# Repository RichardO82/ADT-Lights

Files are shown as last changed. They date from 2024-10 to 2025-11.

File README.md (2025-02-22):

# ADT-Lights

Fish tank light with an LED Strip and additional ambient LEDs controlled by an ESP32 with Annual Daylight Timer (ADT) functionality.

Requires a power supply capable of continuously delivering 4 amps at 5 volts.  Also requires an LED Strip, UV LEDs, a Qwiic Pro Mini microcontroller, and a Qwiic Alphanumeric Display.

Power Supply:
https://www.digikey.com/en/products/detail/mean-well-usa-inc/LRS-35-5/7705043

LED Strip:
https://www.sparkfun.com/products/14015

UV LEDs:
https://www.sparkfun.com/products/8662

Qwiic Pro Mini:
https://www.sparkfun.com/products/23386

Display:
https://www.sparkfun.com/products/16916

All other components are listed in the BOM.  Hardware size is M3x16mm.

Initial Setup:
1.  Update SPIFFS_Uploader.ino with your network ssid and password and flash to ESP32 (configuration settings are in the comments at the top of in ADT_Lights.ino).  This is temporary, we will overwrite the program with ADT_Lights.ino in step 3.
2.  Upload index.html and faders.html to the ESP32 using the uploader.
3.  Flash ADT_Lights.ino to the ESP32.

Start-up and Configuration:

1.  Power on, wait for clock to display.
2.  Using a BLE Terminal App on your phone, find the BLE device "ESP32 LED Bar".
3.  Send your Wifi SSID and password through BLE serial:  To send SSID, send the string ".s[ssid]", where [ssid] is your SSID, for example if my SSID is "FBIVan34" I would send ".sFBIVan34" (without quotes).  Your terminal app may give errors, ignore them.
4.  To send password, send the string ".p[pass]", where [pass] is your password, for example if my password is "apass" I would send ".papass" (without quotes).  After this command the ESP32 will reboot.
5.  After reboot, the ESP32 will connect to your wifi and display it's IP address.  Reboot to display the IP address again if needed by disconnecting and reconnecting power.
6.  In a web browser, type the IP address in the address bar to navigate to the ESP32's webserver and configure the options.

  There are two lighting systems - ambient LEDs, and the LED strip.  The ambient LEDs are not addressable, but they are separated into UV and white channels.  The LED strip is addressable and is configured in a U shape with the 2nd half of the strip turned around and arranged next to the first half, so the strip is two LEDs thick.

  Of the 5 PCBs, one is almost fully populated with components except for two of the LED switching channels (BJT+FET) that arent' being used, while the other 4 PCBs are only populated with LEDs and their current limiting resistors.  Wires carry the drive current to the LEDs on each successive board.  The center LEDs have 3 channels, but they are all white, so I connected these together at the connector (J6 or J7), so I only have two channels (this is why "white" shows up in the code indexed as STRIP_R - I'm using the Red channel for all three).  Originally I wanted a bright white LED, so this is what I shopped for, but I noticed in the datasheet that it has 3 LEDs which are all broken out individually just like an RGB, so I made each one separately dimmable.  It's possible to swap the white LED for an RGB LED and use all 4 channels with minimal changes to the code, but for now everything is made to work with the parts listed using only the two channels for ambient lighting (UV and red for white).  So on the bottom side of the PCB, there are 4 clusters of components which are the BJTs and FETs which step up the signal from the uC and drive the LED channels.  Only the bottom two clusters, the ones that connect to pins 25 and 26 on the Qwiic Pro Mini, need to be populated.

  The PCB which is mostly populated also connects to and supplies power to the LED strip.  The last PCB at the opposite end of the bar is where the middle of the LED strip is split and connected in a U-turn to run back down the bar.  So there are a lot of footprints on the PCBs, but a lot of them are left unpopulated on most of the boards and are only used for specific purposes.  The LED strip will go over some of the unpopulated footprints.  It is important to keep the double sided sticky tape on the LED strip as insulation to prevent contact with the unpopulated footprints on the PCB, and also to secure the strip.

  A couple of things to note, the UV LEDs (sparkfun) have a less than ideal viewing angle (45 deg. on datasheet) that is essentially a narrow beam, so they don't fill the space well and give a striped look.  If there is a UV LED in the same package that has a higher viewing angle, that would be an improvement.  Also, a waterproof closure with UV transmissive acryllic is needed.

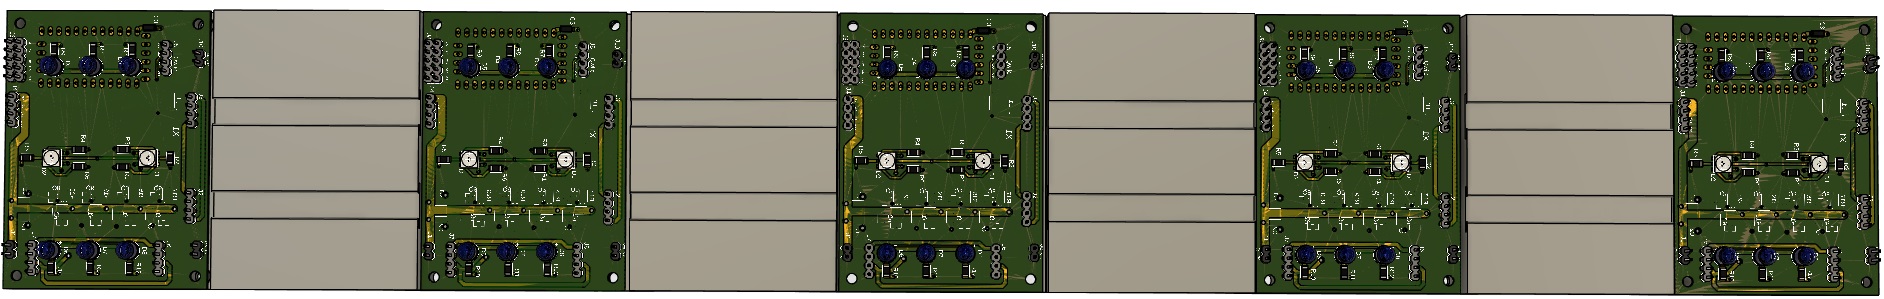
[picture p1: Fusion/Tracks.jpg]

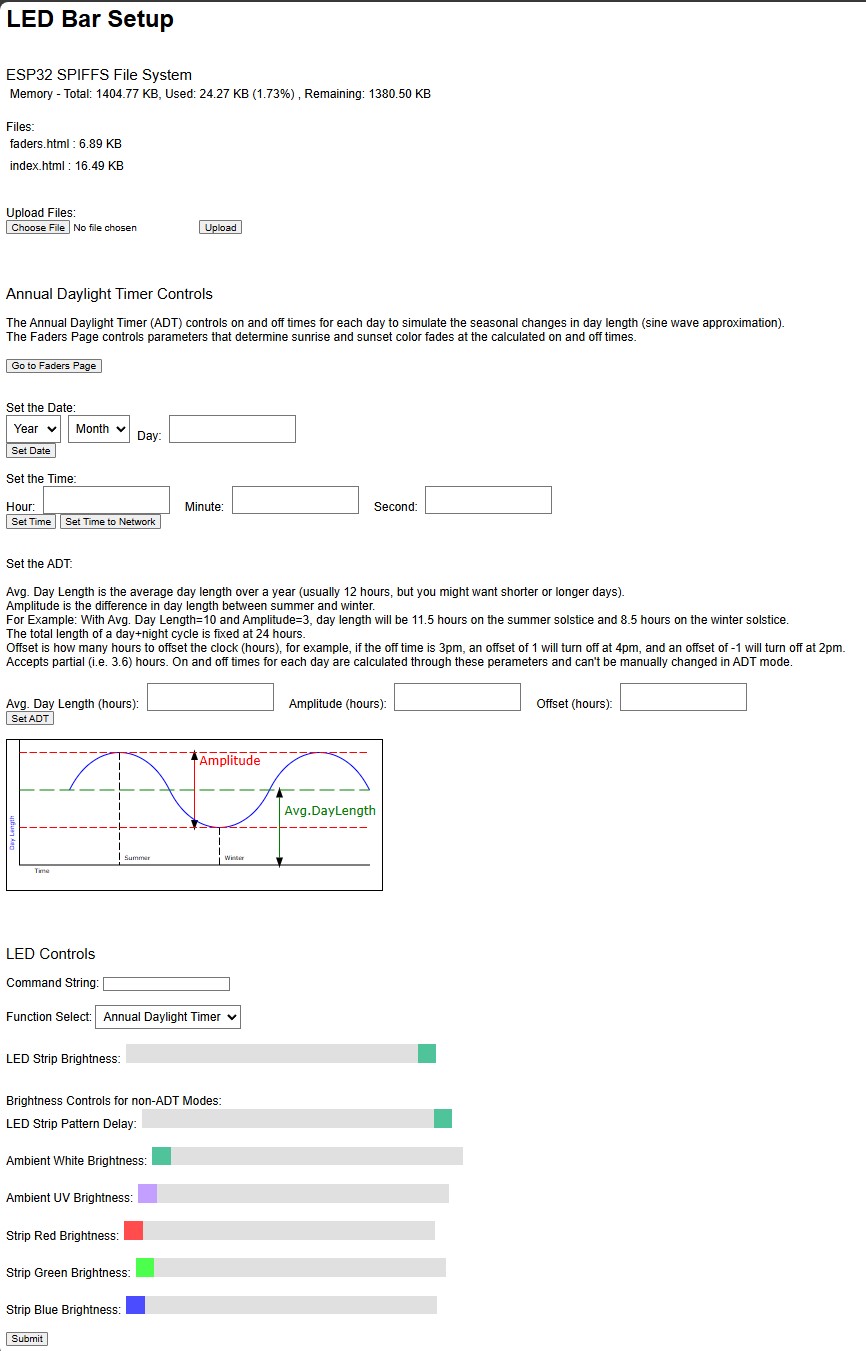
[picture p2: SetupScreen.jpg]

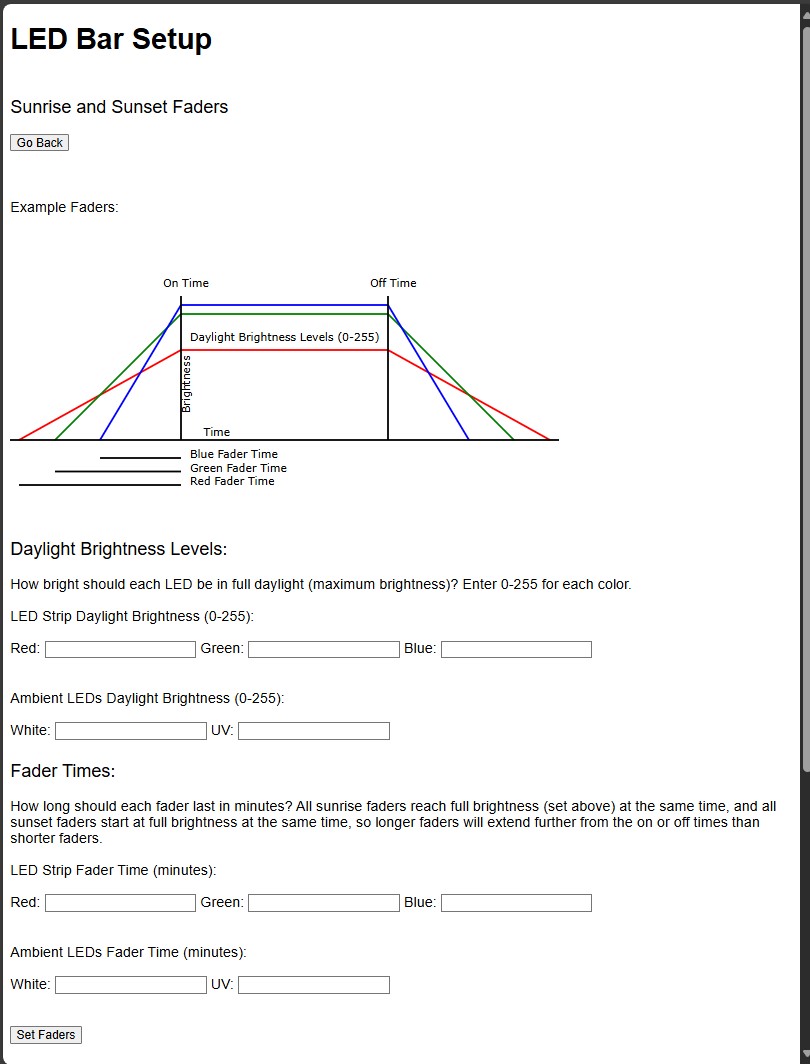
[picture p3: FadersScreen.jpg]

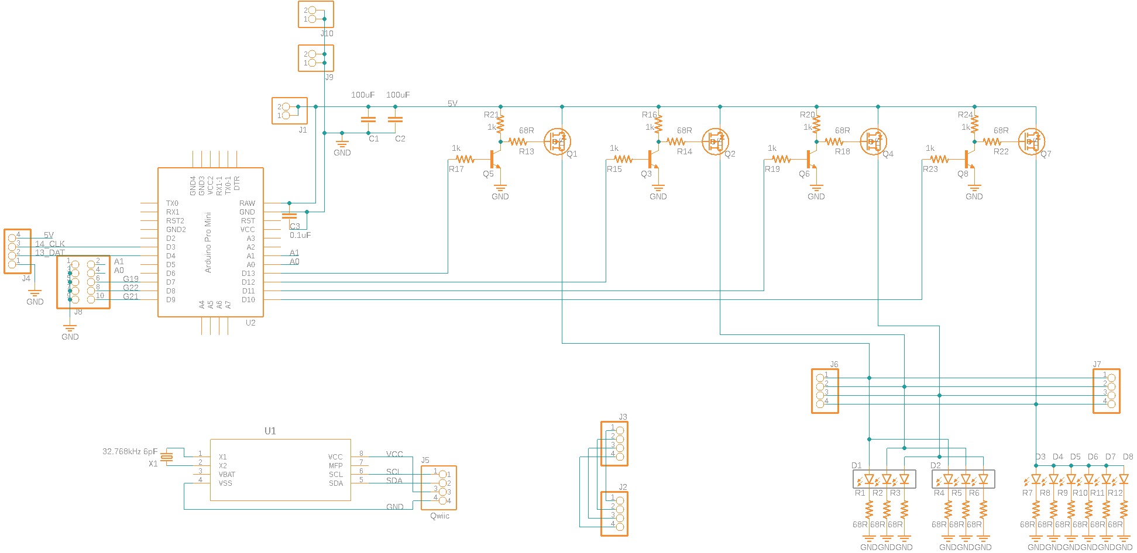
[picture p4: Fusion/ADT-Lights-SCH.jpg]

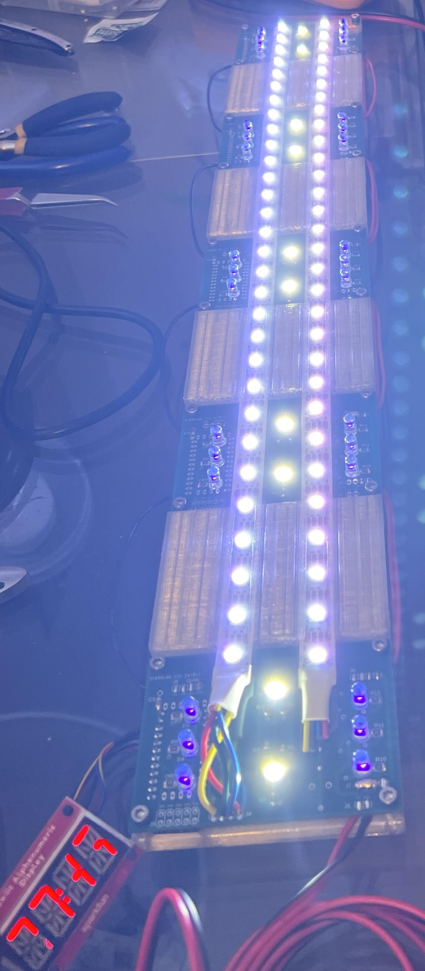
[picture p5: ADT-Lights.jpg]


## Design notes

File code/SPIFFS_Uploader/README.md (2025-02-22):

## Example 2 - Single Webpage, Authentication, File Management, Upload with Progress Bar
- web page authentication
- single webpage
- file listing button
- file download button
- file delete button
- file upload button
- reboot esp32 button
- all done on a single web page that updates webpage elements using javascript

## Configuration
Edit these variables at the beginning of SPIFFS_Uploader.ino

```
const String default_ssid = "somessid";
const String default_wifipassword = "mypassword";
const String default_httpuser = "admin";
const String default_httppassword = "admin";
const int default_webserverporthttp = 80;
```

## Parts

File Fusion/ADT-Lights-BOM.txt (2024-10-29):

"Part";"Value";"Device";"Package";"Description";"AVAILABILITY";"CATEGORY";"COPYRIGHT";"DESC";"DESCRIPTION";"MANUFACTURER";"MANUFACTURER_PART_NUMBER";"MF";"MFR_NAME";"MP";"MPN";"OPERATING_TEMP";"OPERATING_TEMPERATURE";"PACKAGE";"PART_STATUS";"PITCH";"PRICE";"RATING";"ROHS_COMPLIANCE";"ROHS_COMPLIANT";"SERIES";"SHOWNAME";"SUB-CATEGORY";"THERMALLOSS";"TOLERANCE";"TYPE";"VALUE";"VOLTAGE_RATING";
"C1";"100uF";"C_TANTALUM-1206(3216-METRIC)";"CAPM3216X180";"Capacitor - Generic";"";"Capacitor";"";"";"";"";"";"";"";"";"";"";"";"";"";"";"";"";"";"";"";"";"";"";"";"";"";"";
"C2";"100uF";"C_TANTALUM-1206(3216-METRIC)";"CAPM3216X180";"Capacitor - Generic";"";"Capacitor";"";"";"";"";"";"";"";"";"";"";"";"";"";"";"";"";"";"";"";"";"";"";"";"";"";"";
"C3";"0.1uF";"C_TANTALUM-1206(3216-METRIC)";"CAPM3216X180";"Capacitor - Generic";"";"Capacitor";"";"";"";"";"";"";"";"";"NMC1206X7R104K50TRPF";"";"";"";"";"";"";"";"";"";"";"";"";"";"";"";"";"";
"D1";"LED5.4X5X1.6MM";"LED5.4X5X1.6MM";"LED5.4X5X1.6MM";"";"";"";"";"";"";"";"";"";"";"";"  AAAF5060QBFSURZGS";"";"";"";"";"";"";"";"";"";"";"";"";"";"";"";"";"";
"D2";"LED5.4X5X1.6MM";"LED5.4X5X1.6MM";"LED5.4X5X1.6MM";"";"";"";"";"";"";"";"";"";"";"";"";"";"";"";"";"";"";"";"";"";"";"";"";"";"";"";"";"";
"D3";"LED-BLUE";"LED_RADIALBLUE";"LEDRD254W60D565H860B_B";"LED - Generic";"";"";"";"";"";"";"";"";"";"";"";"";"";"";"";"";"";"";"";"";"";"";"";"";"";"";"LED-BLUE";"";
"D4";"LED-BLUE";"LED_RADIALBLUE";"LEDRD254W60D565H860B_B";"LED - Generic";"";"";"";"";"";"";"";"";"";"";"";"";"";"";"";"";"";"";"";"";"";"";"";"";"";"";"LED-BLUE";"";
"D5";"LED-BLUE";"LED_RADIALBLUE";"LEDRD254W60D565H860B_B";"LED - Generic";"";"";"";"";"";"";"";"";"";"";"";"";"";"";"";"";"";"";"";"";"";"";"";"";"";"";"LED-BLUE";"";
"D6";"LED-BLUE";"LED_RADIALBLUE";"LEDRD254W60D565H860B_B";"LED - Generic";"";"";"";"";"";"";"";"";"";"";"";"";"";"";"";"";"";"";"";"";"";"";"";"";"";"";"LED-BLUE";"";
"D7";"LED-BLUE";"LED_RADIALBLUE";"LEDRD254W60D565H860B_B";"LED - Generic";"";"";"";"";"";"";"";"";"";"";"";"";"";"";"";"";"";"";"";"";"";"";"";"";"";"";"LED-BLUE";"";
"D8";"LED-BLUE";"LED_RADIALBLUE";"LEDRD254W60D565H860B_B";"LED - Generic";"";"";"";"";"";"";"";"";"";"";"";"";"";"";"";"";"";"";"";"";"";"";"";"";"";"";"LED-BLUE";"";
"J1";"PINHD-1X02_1X02M";"PINHD-1X02_1X02M";"1X02";"";"";"";"";"";"";"";"";"";"";"";"";"";"";"";"";"";"";"";"";"";"";"";"";"";"";"";"";"";
"J2";"PINHD-1X4";"PINHD-1X4";"1X04";"PIN HEADER";"";"Headers";"";"";"Header, Straight, 4 Position";"Generic";"";"";"";"";"Generic";"";"Generic";"";"Active";"0.100" (2.54mm)";"";"";"Generic";"";"Generic";"";"Headers, Male Pins";"";"";"Board to Board or Cable, Unshrouded, Through Hole, Straight";"PINHD-1X4";"";
"J3";"PINHD-1X4";"PINHD-1X4";"1X04";"PIN HEADER";"";"Headers";"";"";"Header, Straight, 4 Position";"Generic";"";"";"";"";"Generic";"";"Generic";"";"Active";"0.100" (2.54mm)";"";"";"Generic";"";"Generic";"";"Headers, Male Pins";"";"";"Board to Board or Cable, Unshrouded, Through Hole, Straight";"PINHD-1X4";"";
"J4";"PINHD-1X4";"PINHD-1X4";"1X04";"PIN HEADER";"";"Headers";"";"";"Header, Straight, 4 Position";"Generic";"";"";"";"";"Generic";"";"Generic";"";"Active";"0.100" (2.54mm)";"";"";"Generic";"";"Generic";"";"Headers, Male Pins";"";"";"Board to Board or Cable, Unshrouded, Through Hole, Straight";"PINHD-1X4";"";
"J5";"Qwiic";"PINHD-1X04_1X04M";"1X04";"";"";"";"";"Qwiic";"";"";"";"";"";"";"";"";"";"";"";"";"";"";"";"";"";"";"";"";"";"";"";"";
"J6";"PINHD-1X4";"PINHD-1X4";"1X04";"PIN HEADER";"";"Headers";"";"";"Header, Straight, 4 Position";"Generic";"";"";"";"";"Generic";"";"Generic";"";"Active";"0.100" (2.54mm)";"";"";"Generic";"";"Generic";"";"Headers, Male Pins";"";"";"Board to Board or Cable, Unshrouded, Through Hole, Straight";"PINHD-1X4";"";
"J7";"PINHD-1X4";"PINHD-1X4";"1X04";"PIN HEADER";"";"Headers";"";"";"Header, Straight, 4 Position";"Generic";"";"";"";"";"Generic";"";"Generic";"";"Active";"0.100" (2.54mm)";"";"";"Generic";"";"Generic";"";"Headers, Male Pins";"";"";"Board to Board or Cable, Unshrouded, Through Hole, Straight";"PINHD-1X4";"";
"J8";"PINHD-2X5";"PINHD-2X5";"2X05";"PIN HEADER";"";"Headers";"";"";"Header, Straight, 2x5 Position";"Generic";"";"";"";"";"Generic";"";"Generic";"";"Active";"0.100" (2.54mm)";"";"";"Generic";"";"Generic";"";"Headers, Male Pins";"";"";"Board to Board or Cable, Unshrouded, Through Hole, Straight";"PINHD-2X5";"";
"J9";"PINHD-1X02_1X02M";"PINHD-1X02_1X02M";"1X02";"";"";"";"";"";"";"";"";"";"";"";"";"";"";"";"";"";"";"";"";"";"";"";"";"";"";"";"";"";
"J10";"PINHD-1X02_1X02M";"PINHD-1X02_1X02M";"1X02";"";"";"";"";"";"";"";"";"";"";"";"";"";"";"";"";"";"";"";"";"";"";"";"";"";"";"";"";"";
"Q1";"SI2333DDS-T1-GE3SOT-23_TO-236_VIS-L";"SI2333DDS-T1-GE3SOT-23_TO-236_VIS-L";"SOT-23_TO-236_VIS-L";"";"";"";"Copyright (C) 2024 Ultra Librarian. All rights reserved.";"";"";"";"SI2333DDS-T1-GE3";"";"Vishay";"";"";"";"";"";"";"";"";"";"";"";"";"";"";"";"";"";"";"";
"Q2";"SI2333DDS-T1-GE3SOT-23_TO-236_VIS-L";"SI2333DDS-T1-GE3SOT-23_TO-236_VIS-L";"SOT-23_TO-236_VIS-L";"";"";"";"Copyright (C) 2024 Ultra Librarian. All rights reserved.";"";"";"";"SI2333DDS-T1-GE3";"";"Vishay";"";"";"";"";"";"";"";"";"";"";"";"";"";"";"";"";"";"";"";
"Q3";"MMBT3904-7-F";"MMBT3904-7-F";"SOT95P230X110-3N";"NPN SMALL SIGNAL SURFACE MOUNT TRANSISTOR";"Good";"";"";"";" MMBT3904 Series NPN 40 V 300 mW Small Signal Transistor Surface Mount- SOT-23-3 ";"";"";"Diodes Inc.";"";"MMBT3904-7-F";"";"";"";"SOT-23 Diodes Inc.";"";"";"0.04 USD";"";"";"";"";"";"";"";"";"";"";"";
"Q4";"SI2333DDS-T1-GE3SOT-23_TO-236_VIS-L";"SI2333DDS-T1-GE3SOT-23_TO-236_VIS-L";"SOT-23_TO-236_VIS-L";"";"";"";"Copyright (C) 2024 Ultra Librarian. All rights reserved.";"";"";"";"SI2333DDS-T1-GE3";"";"Vishay";"";"";"";"";"";"";"";"";"";"";"";"";"";"";"";"";"";"";"";
"Q5";"MMBT3904-7-F";"MMBT3904-7-F";"SOT95P230X110-3N";"NPN SMALL SIGNAL SURFACE MOUNT TRANSISTOR";"Good";"";"";"";" MMBT3904 Series NPN 40 V 300 mW Small Signal Transistor Surface Mount- SOT-23-3 ";"";"";"Diodes Inc.";"";"MMBT3904-7-F";"";"";"";"SOT-23 Diodes Inc.";"";"";"0.04 USD";"";"";"";"";"";"";"";"";"";"";"";
"Q6";"MMBT3904-7-F";"MMBT3904-7-F";"SOT95P230X110-3N";"NPN SMALL SIGNAL SURFACE MOUNT TRANSISTOR";"Good";"";"";"";" MMBT3904 Series NPN 40 V 300 mW Small Signal Transistor Surface Mount- SOT-23-3 ";"";"";"Diodes Inc.";"";"MMBT3904-7-F";"";"";"";"SOT-23 Diodes Inc.";"";"";"0.04 USD";"";"";"";"";"";"";"";"";"";"";"";
"Q7";"SI2333DDS-T1-GE3SOT-23_TO-236_VIS-L";"SI2333DDS-T1-GE3SOT-23_TO-236_VIS-L";"SOT-23_TO-236_VIS-L";"";"";"";"Copyright (C) 2024 Ultra Librarian. All rights reserved.";"";"";"";"SI2333DDS-T1-GE3";"";"Vishay";"";"";"";"";"";"";"";"";"";"";"";"";"";"";"";"";"";"";"";
"Q8";"MMBT3904-7-F";"MMBT3904-7-F";"SOT95P230X110-3N";"NPN SMALL SIGNAL SURFACE MOUNT TRANSISTOR";"Good";"";"";"";" MMBT3904 Series NPN 40 V 300 mW Small Signal Transistor Surface Mount- SOT-23-3 ";"";"";"Diodes Inc.";"";"MMBT3904-7-F";"";"";"";"SOT-23 Diodes Inc.";"";"";"0.04 USD";"";"";"";"";"";"";"";"";"";"";"";
"R1";"68R";"R-US_CHIP-1206(3216-METRIC)";"RESC3216X70";"Resistor Fixed - ANSI";"";"Resistor";"";"";"";"";"";"";"";"";"";"";"";"";"";"";"";"";"";"";"";"";"Fixed";"";"";"";"";"";
"R2";"68R";"R-US_CHIP-1206(3216-METRIC)";"RESC3216X70";"Resistor Fixed - ANSI";"";"Resistor";"";"";"";"";"";"";"";"";"";"";"";"";"";"";"";"";"";"";"";"";"Fixed";"";"";"";"";"";
"R3";"68R";"R-US_CHIP-1206(3216-METRIC)";"RESC3216X70";"Resistor Fixed - ANSI";"";"Resistor";"";"";"";"";"";"";"";"";"";"";"";"";"";"";"";"";"";"";"";"";"Fixed";"";"";"";"";"";
"R4";"68R";"R-US_CHIP-1206(3216-METRIC)";"RESC3216X70";"Resistor Fixed - ANSI";"";"Resistor";"";"";"";"";"";"";"";"";"";"";"";"";"";"";"";"";"";"";"";"";"Fixed";"";"";"";"";"";
"R5";"68R";"R-US_CHIP-1206(3216-METRIC)";"RESC3216X70";"Resistor Fixed - ANSI";"";"Resistor";"";"";"";"";"";"";"";"";"";"";"";"";"";"";"";"";"";"";"";"";"Fixed";"";"";"";"";"";
"R6";"68R";"R-US_CHIP-1206(3216-METRIC)";"RESC3216X70";"Resistor Fixed - ANSI";"";"Resistor";"";"";"";"";"";"";"";"";"";"";"";"";"";"";"";"";"";"";"";"";"Fixed";"";"";"";"";"";
"R7";"68R";"R-US_CHIP-1206(3216-METRIC)";"RESC3216X70";"Resistor Fixed - ANSI";"";"Resistor";"";"";"";"";"";"";"";"";"";"";"";"";"";"";"";"";"";"";"";"";"Fixed";"";"";"";"";"";
"R8";"68R";"R-US_CHIP-1206(3216-METRIC)";"RESC3216X70";"Resistor Fixed - ANSI";"";"Resistor";"";"";"";"";"";"";"";"";"";"";"";"";"";"";"";"";"";"";"";"";"Fixed";"";"";"";"";"";
"R9";"68R";"R-US_CHIP-1206(3216-METRIC)";"RESC3216X70";"Resistor Fixed - ANSI";"";"Resistor";"";"";"";"";"";"";"";"";"";"";"";"";"";"";"";"";"";"";"";"";"Fixed";"";"";"";"";"";
"R10";"68R";"R-US_CHIP-1206(3216-METRIC)";"RESC3216X70";"Resistor Fixed - ANSI";"";"Resistor";"";"";"";"";"";"";"";"";"";"";"";"";"";"";"";"";"";"";"";"";"Fixed";"";"";"";"";"";
"R11";"68R";"R-US_CHIP-1206(3216-METRIC)";"RESC3216X70";"Resistor Fixed - ANSI";"";"Resistor";"";"";"";"";"";"";"";"";"";"";"";"";"";"";"";"";"";"";"";"";"Fixed";"";"";"";"";"";
"R12";"68R";"R-US_CHIP-1206(3216-METRIC)";"RESC3216X70";"Resistor Fixed - ANSI";"";"Resistor";"";"";"";"";"";"";"";"";"";"";"";"";"";"";"";"";"";"";"";"";"Fixed";"";"";"";"";"";
"R13";"68R";"R-US_CHIP-1206(3216-METRIC)";"RESC3216X70";"Resistor Fixed - ANSI";"";"Resistor";"";"";"";"";"";"";"";"";"";"";"";"";"";"";"";"";"";"";"";"";"Fixed";"";"";"";"";"";
"R14";"68R";"R-US_CHIP-1206(3216-METRIC)";"RESC3216X70";"Resistor Fixed - ANSI";"";"Resistor";"";"";"";"";"";"";"";"";"";"";"";"";"";"";"";"";"";"";"";"";"Fixed";"";"";"";"";"";
"R15";"1k";"R-US_CHIP-1206(3216-METRIC)";"RESC3216X70";"Resistor Fixed - ANSI";"";"Resistor";"";"";"";"";"";"";"";"";"";"";"";"";"";"";"";"";"";"";"";"";"Fixed";"";"";"";"";"";
"R16";"1k";"R-US_CHIP-1206(3216-METRIC)";"RESC3216X70";"Resistor Fixed - ANSI";"";"Resistor";"";"";"";"";"";"";"";"";"";"";"";"";"";"";"";"";"";"";"";"";"Fixed";"";"";"";"";"";
"R17";"1k";"R-US_CHIP-1206(3216-METRIC)";"RESC3216X70";"Resistor Fixed - ANSI";"";"Resistor";"";"";"";"";"";"";"";"";"";"";"";"";"";"";"";"";"";"";"";"";"Fixed";"";"";"";"";"";
"R18";"68R";"R-US_CHIP-1206(3216-METRIC)";"RESC3216X70";"Resistor Fixed - ANSI";"";"Resistor";"";"";"";"";"";"";"";"";"";"";"";"";"";"";"";"";"";"";"";"";"Fixed";"";"";"";"";"";
"R19";"1k";"R-US_CHIP-1206(3216-METRIC)";"RESC3216X70";"Resistor Fixed - ANSI";"";"Resistor";"";"";"";"";"";"";"";"";"";"";"";"";"";"";"";"";"";"";"";"";"Fixed";"";"";"";"";"";
"R20";"1k";"R-US_CHIP-1206(3216-METRIC)";"RESC3216X70";"Resistor Fixed - ANSI";"";"Resistor";"";"";"";"";"";"";"";"";"";"";"";"";"";"";"";"";"";"";"";"";"Fixed";"";"";"";"";"";
"R21";"1k";"R-US_CHIP-1206(3216-METRIC)";"RESC3216X70";"Resistor Fixed - ANSI";"";"Resistor";"";"";"";"";"";"";"";"";"";"";"";"";"";"";"";"";"";"";"";"";"Fixed";"";"";"";"";"";
"R22";"68R";"R-US_CHIP-1206(3216-METRIC)";"RESC3216X70";"Resistor Fixed - ANSI";"";"Resistor";"";"";"";"";"";"";"";"";"";"";"";"";"";"";"";"";"";"";"";"";"Fixed";"";"";"";"";"";
"R23";"1k";"R-US_CHIP-1206(3216-METRIC)";"RESC3216X70";"Resistor Fixed - ANSI";"";"Resistor";"";"";"";"";"";"";"";"";"";"";"";"";"";"";"";"";"";"";"";"";"Fixed";"";"";"";"";"";
"R24";"1k";"R-US_CHIP-1206(3216-METRIC)";"RESC3216X70";"Resistor Fixed - ANSI";"";"Resistor";"";"";"";"";"";"";"";"";"";"";"";"";"";"";"";"";"";"";"";"";"Fixed";"";"";"";"";"";
"U1";"MCP7940MT-I/SNSOIC8-N_MC_MCH-L";"MCP7940MT-I/SNSOIC8-N_MC_MCH-L";"SOIC8-N_MC_MCH-L";"";"";"";"Copyright (C) 2024 Ultra Librarian. All rights reserved.";"";"";"";"MCP7940MT-I/SN";"";"Microchip";"";"";"";"";"";"";"";"";"";"";"";"";"";"";"";"";"";"";"";
"U2";"PRO-MINI";"PRO-MINI";"PRO-MINI";"Arduion Pro Mini Clone V1.0";"";"";"";"";"";"";"";"";"";"";"";"";"";"";"";"";"";"";"";"";"";"U2";"";"";"";"";"";"";
"X1";"32.768kHz 6pF";"XTAL_32.768_CM13032768DZCT";"CM130";"";"";"";"";"";"";"";"";"";"";"";"CM13032768DZCT";"";"";"";"";"";"";"";"";"";"";"";"";"";"";"";"";"";

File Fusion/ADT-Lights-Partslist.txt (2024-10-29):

"Qty";"Value";"Device";"Package";"Parts";"Description";"AVAILABILITY";"CATEGORY";"COPYRIGHT";"DESC";"DESCRIPTION";"MANUFACTURER";"MANUFACTURER_PART_NUMBER";"MF";"MFR_NAME";"MP";"MPN";"OPERATING_TEMP";"OPERATING_TEMPERATURE";"PACKAGE";"PART_STATUS";"PITCH";"PRICE";"RATING";"ROHS_COMPLIANCE";"ROHS_COMPLIANT";"SERIES";"SHOWNAME";"SUB-CATEGORY";"THERMALLOSS";"TOLERANCE";"TYPE";"VALUE";"VOLTAGE_RATING";
"1";"0.1uF";"C_TANTALUM-1206(3216-METRIC)";"CAPM3216X180";"C3";"Capacitor - Generic";"";"Capacitor";"";"";"";"";"";"";"";"";"NMC1206X7R104K50TRPF";"";"";"";"";"";"";"";"";"";"";"";"";"";"";"";"";"";
"2";"100uF";"C_TANTALUM-1206(3216-METRIC)";"CAPM3216X180";"C1, C2";"Capacitor - Generic";"";"Capacitor";"";"";"";"";"";"";"";"";"";"";"";"";"";"";"";"";"";"";"";"";"";"";"";"";"";"";
"8";"1k";"R-US_CHIP-1206(3216-METRIC)";"RESC3216X70";"R15, R16, R17, R19, R20, R21, R23, R24";"Resistor Fixed - ANSI";"";"Resistor";"";"";"";"";"";"";"";"";"";"";"";"";"";"";"";"";"";"";"";"";"Fixed";"";"";"";"";"";
"1";"32.768kHz 6pF";"XTAL_32.768_CM13032768DZCT";"CM130";"X1";"";"";"";"";"";"";"";"";"";"";"";"CM13032768DZCT";"";"";"";"";"";"";"";"";"";"";"";"";"";"";"";"";"";
"16";"68R";"R-US_CHIP-1206(3216-METRIC)";"RESC3216X70";"R1, R2, R3, R4, R5, R6, R7, R8, R9, R10, R11, R12, R13, R14, R18, R22";"Resistor Fixed - ANSI";"";"Resistor";"";"";"";"";"";"";"";"";"";"";"";"";"";"";"";"";"";"";"";"";"Fixed";"";"";"";"";"";
"6";"LED-BLUE";"LED_RADIALBLUE";"LEDRD254W60D565H860B_B";"D3, D4, D5, D6, D7, D8";"LED - Generic";"";"";"";"";"";"";"";"";"";"";"";"";"";"";"";"";"";"";"";"";"";"";"";"";"";"";"LED-BLUE";"";
"1";"LED5.4X5X1.6MM";"LED5.4X5X1.6MM";"LED5.4X5X1.6MM";"D1";"";"";"";"";"";"";"";"";"";"";"";"  AAAF5060QBFSURZGS";"";"";"";"";"";"";"";"";"";"";"";"";"";"";"";"";"";
"1";"LED5.4X5X1.6MM";"LED5.4X5X1.6MM";"LED5.4X5X1.6MM";"D2";"";"";"";"";"";"";"";"";"";"";"";"";"";"";"";"";"";"";"";"";"";"";"";"";"";"";"";"";"";
"1";"MCP7940MT-I/SNSOIC8-N_MC_MCH-L";"MCP7940MT-I/SNSOIC8-N_MC_MCH-L";"SOIC8-N_MC_MCH-L";"U1";"";"";"";"Copyright (C) 2024 Ultra Librarian. All rights reserved.";"";"";"";"MCP7940MT-I/SN";"";"Microchip";"";"";"";"";"";"";"";"";"";"";"";"";"";"";"";"";"";"";"";
"4";"MMBT3904-7-F";"MMBT3904-7-F";"SOT95P230X110-3N";"Q3, Q5, Q6, Q8";"NPN SMALL SIGNAL SURFACE MOUNT TRANSISTOR";"Good";"";"";"";" MMBT3904 Series NPN 40 V 300 mW Small Signal Transistor Surface Mount- SOT-23-3 ";"";"";"Diodes Inc.";"";"MMBT3904-7-F";"";"";"";"SOT-23 Diodes Inc.";"";"";"0.04 USD";"";"";"";"";"";"";"";"";"";"";"";
"3";"PINHD-1X02_1X02M";"PINHD-1X02_1X02M";"1X02";"J1, J9, J10";"";"";"";"";"";"";"";"";"";"";"";"";"";"";"";"";"";"";"";"";"";"";"";"";"";"";"";"";"";
"5";"PINHD-1X4";"PINHD-1X4";"1X04";"J2, J3, J4, J6, J7";"PIN HEADER";"";"Headers";"";"";"Header, Straight, 4 Position";"Generic";"";"";"";"";"Generic";"";"Generic";"";"Active";"0.100" (2.54mm)";"";"";"Generic";"";"Generic";"";"Headers, Male Pins";"";"";"Board to Board or Cable, Unshrouded, Through Hole, Straight";"PINHD-1X4";"";
"1";"PINHD-2X5";"PINHD-2X5";"2X05";"J8";"PIN HEADER";"";"Headers";"";"";"Header, Straight, 2x5 Position";"Generic";"";"";"";"";"Generic";"";"Generic";"";"Active";"0.100" (2.54mm)";"";"";"Generic";"";"Generic";"";"Headers, Male Pins";"";"";"Board to Board or Cable, Unshrouded, Through Hole, Straight";"PINHD-2X5";"";
"1";"PRO-MINI";"PRO-MINI";"PRO-MINI";"U2";"Arduion Pro Mini Clone V1.0";"";"";"";"";"";"";"";"";"";"";"";"";"";"";"";"";"";"";"";"";"";"U2";"";"";"";"";"";"";
"1";"Qwiic";"PINHD-1X04_1X04M";"1X04";"J5";"";"";"";"";"Qwiic";"";"";"";"";"";"";"";"";"";"";"";"";"";"";"";"";"";"";"";"";"";"";"";"";
"4";"SI2333DDS-T1-GE3SOT-23_TO-236_VIS-L";"SI2333DDS-T1-GE3SOT-23_TO-236_VIS-L";"SOT-23_TO-236_VIS-L";"Q1, Q2, Q4, Q7";"";"";"";"Copyright (C) 2024 Ultra Librarian. All rights reserved.";"";"";"";"SI2333DDS-T1-GE3";"";"Vishay";"";"";"";"";"";"";"";"";"";"";"";"";"";"";"";"";"";"";"";

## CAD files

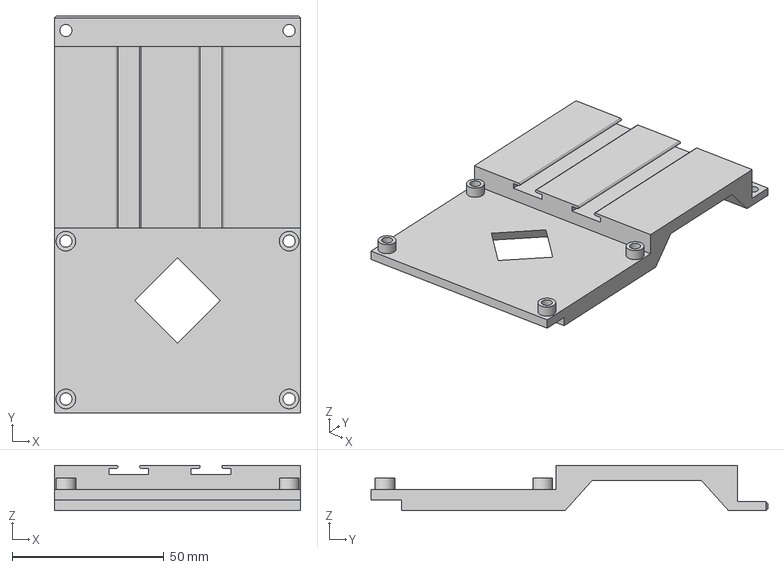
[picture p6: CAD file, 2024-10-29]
Fusion/ADT-Lights Tracks v13 body1.step
81.3 x 131.0 x 15.0 mm

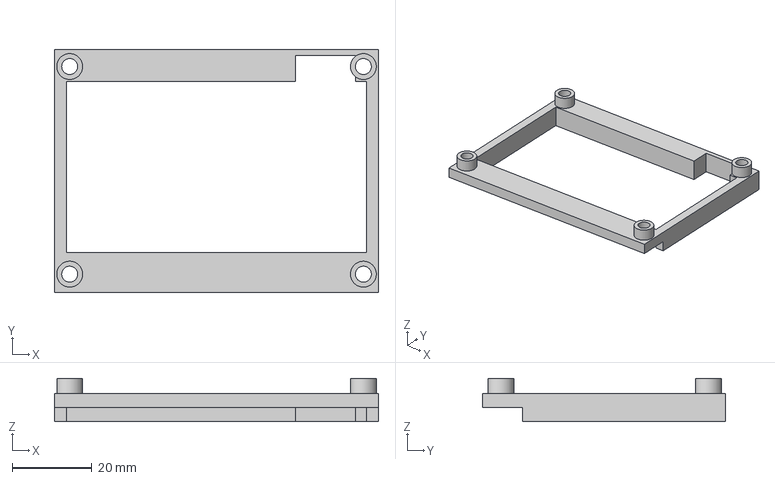
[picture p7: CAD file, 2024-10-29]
Fusion/ADT-Lights Tracks v13 body9.step
81.3 x 61.0 x 10.8 mm

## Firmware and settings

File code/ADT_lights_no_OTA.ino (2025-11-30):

// Arduino IDE settings: 

//               Board: ESP32 Dev Module
//          Flash size: 8MB
//    Partition Scheme: 8MB with SPIFFS
//               PSRAM: Enabled



// To-Do:
//    * Add fields to and prefs to set gmt offset, daylight savings, ntp server.
//    * Display current settings next to new settings fields


////////////////////////////////////////////////////////////////////////////////////////////////////
////////////////////////////////////////////////////////////////////////////////////////////////////
////////////////////////////////////////////////////////////////////////////////////////////////////

/////   Code and Language Setup

////////////////////////////////////////////////////////////////////////////////////////////////////
////////////////////////////////////////////////////////////////////////////////////////////////////
////////////////////////////////////////////////////////////////////////////////////////////////////


///////////////////////// || Includes || /////////////////////////
#include <APA102.h>
#include <Arduino.h>
#include <ArduinoJson.h>
#include <ArduinoOTA.h>
#include <BLE2902.h>
#include <BLEDevice.h>
#include <BLEServer.h>
#include <BLEUtils.h>
#include <ESPAsyncWebServer.h>
#include <ESPmDNS.h>
#include <MCP7940.h>
#include <NetworkUdp.h>
#include <Preferences.h>
#include <SparkFun_Alphanumeric_Display.h> //Click here to get the library: http://librarymanager/All#SparkFun_Qwiic_Alphanumeric_Display by SparkFun
#include <SPIFFS.h>
#include <time.h>
#include <WiFi.h>
#include <Wire.h>


///////////////////////// || Defines || /////////////////////////
#define DB_PIN 0
#define LED_UV 26
#define LED_R 25
#define LED_G 33
#define LED_B 32 
#define PWM_FREQ 5000     // Frequency in Hz
#define PWM_RESOLUTION 8  // 8-bit resolution (0 - 255)

#define SERVICE_UUID           "6E400001-B5A3-F393-E0A9-E50E24DCCA9E"  // UART service UUID
#define CHARACTERISTIC_UUID_RX "6E400002-B5A3-F393-E0A9-E50E24DCCA9E"
#define CHARACTERISTIC_UUID_TX "6E400003-B5A3-F393-E0A9-E50E24DCCA9E"

#define NUM_STATES  9  // number of patterns to cycle through
#define LED_COUNT 30
#define RECSTR_LIMIT  64
#define BLE_STR_TIME  500 // time limit between characters determines inclusion in string from ble

#define TIMEINDAY   86400   // seconds in a day

#define NUM_FADERS 7
#define STRIP_R   0
#define STRIP_G   1
#define STRIP_B   2
#define AMBI_R    3
#define AMBI_G    4
#define AMBI_B    5
#define AMBI_UV   6



///////////////////////// || Variables || /////////////////////////

const char* ntpServer = "pool.ntp.org";
const long gmtOffset_sec = -28800; // Adjust for your timezone (e.g., -8 hours for PST)
const int daylightOffset_sec = 3600; // Adjust for daylight saving (if applicable)

bool otaActive = false;


// ADT Variables

unsigned long on_sec, off_sec;    // Calculated times of day (in seconds) for seasonally adjusted sunrise and sunset.

uint8_t DayBrightness[NUM_FADERS];       // "Full" brightness for this color in daytime, after fading up.
unsigned int FadeSeconds[NUM_FADERS];   // How many seconds for the fade? (On / Off times determined by ADT [on_sec and off_sec times are at 100% Daybrights])
double DutyCycles[NUM_FADERS];       // Current duty cycles for each fader

unsigned int amplitude = 14400;   // 4 hrs
unsigned int avgday = 43200;      // 12 hrs
int offset = 7200;       // 2 hrs

unsigned int last_day = 0;
unsigned int last_month = 0;

int psRAMsize, psRAMfree;

uint8_t stripDelay = 1;

const char* htmlPath = "/index.html";
//const char* dataPath = "/data.json";

String files_json = "Default Name";

HT16K33 display;

Preferences prefs;

bool WifiOK = false;

int anInt;
int anotherInt;
char aChar;
float aFloat;
float aFloat2;
float aFloat3;
float aFloat4;
String aString;

//const uint32_t SERIAL_SPEED{115200};     // Set the baud rate for Serial I/O
//const uint8_t  LED_PIN{13};              // Arduino built-in LED pin number
const uint8_t  SPRINTF_BUFFER_SIZE{32};  // Buffer size for sprintf()
MCP7940_Class MCP7940;                           // Create an instance of the MCP7940
char          inputBuffer[SPRINTF_BUFFER_SIZE];  // Buffer for sprintf()/sscanf()
DateTime       nowRTC;
uint8_t       last_sec, this_sec;


unsigned int bootCnt=0;

rgb_color colors[LED_COUNT*2];

String ssid;
String password;
AsyncWebServer server(80);    // Create AsyncWebServer object on port 80


uint8_t spot_led = 0;

const uint8_t dataPin = 13;
const uint8_t clockPin = 14;
APA102<dataPin, clockPin> ledStrip;

uint8_t globalBrightness = 31;    // Set the brightness to use (the maximum is 31).


unsigned int maxLoops;
unsigned int loopCount = 0;   // system timer, incremented by one every time through the main loop
unsigned int seed = 0;  // used to initialize random number generator



enum Pattern {      // enumerate the functional modes
  AnnualDaylightTimer = 0,
  WarmWhiteShimmer = 1,
  RandomColorWalk = 2,
  TraditionalColors = 3,
  ColorExplosion = 4,
  Gradient = 5,
  BrightTwinkle = 6,
  Collision = 7,
  AllBright = 8,
  SingleSpot = 9,
  AllManual = 10,
  AllOff = 255
};
unsigned char pattern = AnnualDaylightTimer;


String RecString;
unsigned long last_rec = 0; // time (millis) of last receive for determining string inclusion.  0 = not receiving a string.
unsigned long this_rec = 0;
unsigned char Received = 0;   // Single char receive buffer
uint8_t str_cnt = 0;          // Counter for string mode
uint8_t led_timer = 0;      // Convert from waiting 20 ms to counting 10 waits of 2 ms...


BLEServer *pServer = NULL;
BLECharacteristic *pTxCharacteristic;
bool deviceConnected = false;
bool oldDeviceConnected = false;
uint8_t txValue = 0;



///////////////////////// || BLE Classes || /////////////////////////

class MyServerCallbacks : public BLEServerCallbacks {
  void onConnect(BLEServer *pServer) {
    deviceConnected = true;
  };

  void onDisconnect(BLEServer *pServer) {
    deviceConnected = false;
  }
};

class MyCallbacks : public BLECharacteristicCallbacks {
  void onWrite(BLECharacteristic *pCharacteristic) {
    String rxValue = pCharacteristic->getValue();

    if (rxValue.length() > 0) {
      Serial.println("*********");
      Serial.print("Received Value: ");
      for (int i = 0; i < rxValue.length(); i++) {
        Serial.print(rxValue[i]);
        Received = rxValue[i];
      }

      //Serial.println();
      //Serial.println("*********");
    }
  }
};


////////////////////////////////////////////////////////////////////////////////////////////////////
////////////////////////////////////////////////////////////////////////////////////////////////////
////////////////////////////////////////////////////////////////////////////////////////////////////

/////   Setup and Loop Functions

////////////////////////////////////////////////////////////////////////////////////////////////////
////////////////////////////////////////////////////////////////////////////////////////////////////
////////////////////////////////////////////////////////////////////////////////////////////////////

////////////////////////////////////////////////////////////////////////////////////////////////////////////

// function defaults
//String listFiles(bool ishtml = false);

void setup()
{
  Serial.begin(115200);


  Serial.print(F("- Compiled with c++ version "));
  Serial.print(F(__VERSION__));  // Show compiler information
  Serial.print(F("\n- On "));
  Serial.print(F(__DATE__));
  Serial.print(F(" at "));
  Serial.print(F(__TIME__));
  Serial.print(F("\n"));


  ////////////////////// Initialize SPIFFS /////////////////////////////////////
  if (!SPIFFS.begin(true)) {
    Serial.println("SPIFFS initialization failed!");
    return;
  }
  else Serial.println("SPIFFS Initialized.");

  Serial.print("SPIFFS Free: "); Serial.println(humanReadableSize((SPIFFS.totalBytes() - SPIFFS.usedBytes())));
  Serial.print("SPIFFS Used: "); Serial.println(humanReadableSize(SPIFFS.usedBytes()));
  Serial.print("SPIFFS Total: "); Serial.println(humanReadableSize(SPIFFS.totalBytes()));

  Serial.println(listFiles());


  /////////////// I2C Stuff ////////////////////////////////////////////////
  Wire.begin(15, 5);  // ESP32 Qwiic Pro Mini I2C pins.

  if (display.begin() == false)
  {
    Serial.println("Device did not acknowledge! Freezing.");
    while (1);
  }
  Serial.println("Display acknowledged.");
  
  display.setBrightness(1);   // ints between 0 (1/16 brightness) and 15 (full brightness)
  
  display.print("ADT ");
  

  ////////////// Preferences //////////////////////////////////
  prefs.begin("LED_Bar_data", false);

    prefs.getUInt("bootCnt", bootCnt);
    bootCnt++;
    prefs.putUInt("bootCnt", bootCnt);

  prefs.end();

  prefs.begin("Wifi", false);
    ssid = prefs.getString("ssid", " ");
    password = prefs.getString("password", " ");
  prefs.end();  


  prefs.begin("ADT", false);
    amplitude = prefs.getUInt("amplitude", 14400);
    avgday = prefs.getUInt("avgday", 43200);
    offset = prefs.getUInt("offset", 0);
  prefs.end();

  prefs.begin("faders", false);
    DayBrightness[STRIP_R] = prefs.getUInt("stripRday", 230);    
    DayBrightness[STRIP_G] = prefs.getUInt("stripGday", 100);    
    DayBrightness[STRIP_B] = prefs.getUInt("stripBday", 255);    
  
    DayBrightness[AMBI_R] = prefs.getUInt("ambiRday", 200);    
    DayBrightness[AMBI_G] = prefs.getUInt("ambiGday", 180);    
    DayBrightness[AMBI_B] = prefs.getUInt("ambiBday", 150);    
    DayBrightness[AMBI_UV] = prefs.getUInt("ambiUVday", 0);    
  
    FadeSeconds[STRIP_R] = prefs.getUInt("stripRfade", 2000);    
    FadeSeconds[STRIP_G] = prefs.getUInt("stripGfade", 1800);    
    FadeSeconds[STRIP_B] = prefs.getUInt("stripBfade", 1500);    
  
    FadeSeconds[AMBI_R] = prefs.getUInt("ambiRfade", 1800);    
    FadeSeconds[AMBI_G] = prefs.getUInt("ambiGfade", 1800);    
    FadeSeconds[AMBI_B] = prefs.getUInt("ambiBfade", 1500);    
    FadeSeconds[AMBI_UV] = prefs.getUInt("ambiUVfade", 1800);    
  
    for(int i=0; i < NUM_FADERS; i++) DutyCycles[i] = 0;
  prefs.end();


  //////////////// LED Lighting ///////////////////////////////////////////
  // initialize the random number generator with a seed obtained by
  // summing the voltages on the disconnected analog inputs
  for (int i = 0; i < 8; i++)
  {
    seed += analogRead(i);
  }
  seed += random(256);
  randomSeed(seed);
/*
  for(int i=0; i < NUM_FADERS; i++) {    // Set initial conditions for faders
    DayBrightness[i] = 200;
    FadeSeconds[i] = 400;
    DutyCycles[i] = 0;
  }
  DayBrightness[AMBI_UV] = 0;     // Return the UV to off;
  
  FadeSeconds[STRIP_R] =  2400;
  FadeSeconds[STRIP_G] =  1800;
  DayBrightness[STRIP_B] = 100;
  DayBrightness[STRIP_G] = 100;
*/
  pinMode(DB_PIN, OUTPUT);

  ledcAttach(LED_UV, PWM_FREQ, PWM_RESOLUTION);
  ledcAttach(LED_R, PWM_FREQ, PWM_RESOLUTION);
  ledcAttach(LED_G, PWM_FREQ, PWM_RESOLUTION);
  ledcAttach(LED_B, PWM_FREQ, PWM_RESOLUTION);


  delay(10);  // give pull-ups time raise the input voltage





  ////////////////// BLE //////////////////////////////////////////////

  // Create the BLE Device
  BLEDevice::init("ESP32 LED Bar");

  // Create the BLE Server
  pServer = BLEDevice::createServer();
  pServer->setCallbacks(new MyServerCallbacks());

  // Create the BLE Service
  BLEService *pService = pServer->createService(SERVICE_UUID);

  // Create a BLE Characteristic
  pTxCharacteristic = pService->createCharacteristic(CHARACTERISTIC_UUID_TX, BLECharacteristic::PROPERTY_NOTIFY);

  pTxCharacteristic->addDescriptor(new BLE2902());

  BLECharacteristic *pRxCharacteristic = pService->createCharacteristic(CHARACTERISTIC_UUID_RX, BLECharacteristic::PROPERTY_WRITE);

  pRxCharacteristic->setCallbacks(new MyCallbacks());

  // Start the service
  pService->start();

  // Start advertising
  pServer->getAdvertising()->start();
  Serial.println("Waiting a client connection to notify...");


  
  /////////////// Wifi /////////////////////////////////////////////////

  WiFi.mode(WIFI_STA);
  

  WiFi.begin(ssid, password);

  Serial.println("Creds:");
  Serial.println(ssid);
  Serial.println(password);
  
  for(int i = 0; i < 3; i++) {
    if(WiFi.waitForConnectResult() != WL_CONNECTED) delay(100);
    else WifiOK = true;
  } 

  if(WifiOK) {
    
    
    String ipStr = WiFi.localIP().toString();


    // Split the IP into its individual octets
    int firstDot = ipStr.indexOf('.');
    int secondDot = ipStr.indexOf('.', firstDot + 1);
    int thirdDot = ipStr.indexOf('.', secondDot + 1);

    String octet1 = ipStr.substring(0, firstDot);
    String octet2 = ipStr.substring(firstDot + 1, secondDot);
    String octet3 = ipStr.substring(secondDot + 1, thirdDot);
    String octet4 = ipStr.substring(thirdDot + 1);


    display.print(octet1);
    delay(1000);
    display.print(octet2);
    delay(1000);
    display.print(octet3);
    delay(1000);
    display.print(octet4);
    delay(1000);

  }




  ////////////// RTC /////////////////////////////////////////
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
void loop()
{
  uint8_t startTime = millis();  
  psRAMsize = ESP.getPsramSize();
  psRAMfree = ESP.getFreePsram();

  if(otaActive) {
    ArduinoOTA.handle();
    delay(1);
  }
  delay(10);   // don't hog the CPU, give some time to AWS

  if(led_timer > stripDelay) {

    ///////////////////// RTC and Clock Display //////////////////////////////
    nowRTC = MCP7940.now();  // get the current time
    this_sec = nowRTC.second();
    
    if(this_sec != last_sec) {    
      last_sec = this_sec;
      if((last_sec % 2) != 0) sprintf(inputBuffer, "%02d:%02d", nowRTC.hour(), nowRTC.minute());
      else sprintf(inputBuffer, "%02d%02d", nowRTC.hour(), nowRTC.minute());
      display.print(inputBuffer);
    }

    //////////////////// LED Strip /////////////////////////////////////////////////////////////
    if (loopCount == 0) {
      for (int i = 0; i < LED_COUNT; i++) {
        colors[i] = rgb_color(0, 0, 0);     // whenever timer resets, clear the LED colors array (all off)
      }
    }    
    
    process_patterns();

    for(int i=0; i < LED_COUNT; i++) colors[LED_COUNT+i] = colors[LED_COUNT-i-1];  // Mirror the half populated strip (U-turn)
    ledStrip.write(colors, LED_COUNT*2, globalBrightness);
    
    digitalWrite(DB_PIN, HIGH);
    ledcWrite(LED_UV, DutyCycles[AMBI_UV]);
    ledcWrite(LED_R, DutyCycles[AMBI_R]);
    ledcWrite(LED_G, DutyCycles[AMBI_G]);
    ledcWrite(LED_B, DutyCycles[AMBI_B]);


    ////////////////// Handle BLE Messages ////////////////////////////////////////
    if(last_rec != 0) this_rec = millis();
    else this_rec = 0;
    if((this_rec - last_rec) > BLE_STR_TIME) {
      last_rec = 0;   
      CommandString(RecString);
    }

    if(Received != 0) {
      if(last_rec == 0) {
        CommandChar(Received);
        Received = 0;
      }
      else {
        if (RecString.length() <= str_cnt) {      // Append enough characters manually to extend the length
          while (RecString.length() <= str_cnt) {
            RecString += ' ';  // Add space characters to expand the string
          }
        }

        RecString.setCharAt(str_cnt, Received);
        Received = 0;
        str_cnt++;
        last_rec = this_rec;
      }
    }
  }

  ////////////////// BLE Processing ////////////////////////////
  if (deviceConnected) {
    pTxCharacteristic->setValue(&txValue, 1);
    pTxCharacteristic->notify();
    txValue++;
    delay(10);  // bluetooth stack will go into congestion, if too many packets are sent
  }

  if (!deviceConnected && oldDeviceConnected) {   // disconnecting
    delay(500);                   // give the bluetooth stack the chance to get things ready
    pServer->startAdvertising();  // restart advertising
    Serial.println("start advertising");
    oldDeviceConnected = deviceConnected;
  }
  if (deviceConnected && !oldDeviceConnected) {   // connecting
    // do stuff here on connecting
    oldDeviceConnected = deviceConnected;
  }




  //////////////// TIMING //////////////////////////////////////
  if(led_timer > stripDelay) led_timer = 0;
  while((uint8_t)(millis() - startTime) < 1) { }
  led_timer++;
  if(led_timer > stripDelay) loopCount++;  // increment our loop counter/timer.

  digitalWrite(DB_PIN, LOW);
  
}


























////////////////////////////////////////////////////////////////////////////////////////////////////
////////////////////////////////////////////////////////////////////////////////////////////////////
////////////////////////////////////////////////////////////////////////////////////////////////////

/////   Functions

////////////////////////////////////////////////////////////////////////////////////////////////////
////////////////////////////////////////////////////////////////////////////////////////////////////
////////////////////////////////////////////////////////////////////////////////////////////////////


void ReCalcADT(void) {
  float yearFraction;
  float now_amplitude;
  float on_time, off_time;
  
  switch(nowRTC.month())
  {
    case 1:
      yearFraction = nowRTC.day() - 1.0;
      break;
    case 2:
      yearFraction = nowRTC.day() + 30.0;
      break;
    case 3:
      yearFraction = nowRTC.day() + 58.0;
      break;
    case 4:
      yearFraction = nowRTC.day() + 89.0;
      break;
    case 5:
      yearFraction = nowRTC.day() + 119.0;
      break;
    case 6:
      yearFraction = nowRTC.day() + 150.0;
      break;
    case 7:
      yearFraction = nowRTC.day() + 180.0;
      break;
    case 8:
      yearFraction = nowRTC.day() + 211.0;
      break;
    case 9:
      yearFraction = nowRTC.day() + 242.0;
      break;
    case 10:
      yearFraction = nowRTC.day() + 272.0;
      break;
    case 11:
      yearFraction = nowRTC.day() + 303.0;
      break;
    case 12:
      yearFraction = nowRTC.day() + 333.0;
      break;
  }

  yearFraction += 171.0;    // Offset calendar so that day 0 is Jun 21 (Spring Equinox)
  if(yearFraction > 365.0) yearFraction -= 365.0;

  yearFraction = yearFraction / 365.0;

  now_amplitude = cos( 2 * PI * yearFraction) * amplitude + avgday;

  on_time = TIMEINDAY / 2.0 - now_amplitude / 2.0;
  off_time = on_time + now_amplitude;

  on_sec = round(on_time) + offset;
  off_sec = round(off_time) + offset;  
}


void process_patterns(void) {
  if (pattern == WarmWhiteShimmer || pattern == RandomColorWalk)
  {
    // for these two patterns, we want to make sure we get the same
    // random sequence six times in a row (this provides smoother
    // random fluctuations in brightness/color)
    if (loopCount % 6 == 0)
    {
      seed = random(30000);
    }
    randomSeed(seed);
  }

  // call the appropriate pattern routine based on state; these
  // routines just set the colors in the colors array
  switch (pattern)
  {
    case AnnualDaylightTimer:
      int secofday;
      float fade_level;
      int i;

      if( (nowRTC.day() != last_day) || (nowRTC.month() != last_month) ) {    // Do a ReCalc if the day or month has changed
        last_day = nowRTC.day();
        last_month = nowRTC.month();
        ReCalcADT();
      }

      secofday = nowRTC.hour() * 60 * 60 + nowRTC.minute() * 60 + nowRTC.second();

      for( i = 0; i < NUM_FADERS; i++ ) {
        // determine ON-ness via slope of %max-duty per second
        fade_level = ((float)DayBrightness[i]/255.0) / (float)FadeSeconds[i] * ((float)secofday - (float)on_sec) + ((float)DayBrightness[i]/255.0);
        DutyCycles[i] = round(fade_level * 255.0);

        // determine OFF-ness via slope of %max-duty per second
        if(secofday > on_sec + 1) {           // Let the Fade in do it's thing first
          fade_level = ((float)DayBrightness[i] / -255.0) / (float)FadeSeconds[i] * ((float)secofday - (float)off_sec) + ((float)DayBrightness[i]/255.0);
          DutyCycles[i] = round(fade_level * 255.0);
        }

        if( DutyCycles[i]  > DayBrightness[i] ) DutyCycles[i] = DayBrightness[i];
        if( DutyCycles[i] < 0) DutyCycles[i] = 0;
      }
  
      for( i = 0; i < LED_COUNT; i++ ) {
        colors[i] = rgb_color(DutyCycles[STRIP_R], DutyCycles[STRIP_G], DutyCycles[STRIP_B]);
      }
      break;

    case WarmWhiteShimmer:
      // warm white shimmer for 300 loopCounts, fading over last 70
      maxLoops = 300;
      warmWhiteShimmer(loopCount > maxLoops - 70);
      if(loopCount > maxLoops) loopCount = 0; // continue forever
      break;

    case RandomColorWalk:
      // start with alternating red and green colors that randomly walk
      // to other colors for 400 loopCounts, fading over last 80
      maxLoops = 400;
      randomColorWalk(loopCount == 0 ? 1 : 0, loopCount > maxLoops - 80);
      if(loopCount > maxLoops) loopCount = 0; // continue forever
      break;

    case TraditionalColors:
      // repeating pattern of red, green, orange, blue, magenta that
      // slowly moves for 400 loopCounts
      maxLoops = 400;
      traditionalColors();
      break;

    case ColorExplosion:
      // bursts of random color that radiate outwards from random points
      // for 630 loop counts; no burst generation for the last 70 counts
      // of every 200 count cycle or over the over final 100 counts
      // (this creates a repeating bloom/decay effect)
      maxLoops = 630;
      colorExplosion((loopCount % 200 > 130) || (loopCount > maxLoops - 100));
      if(loopCount > maxLoops) loopCount = 0; // continue forever
      break;

    case Gradient:
      // red -> white -> green -> white -> red ... gradiant that scrolls
      // across the strips for 250 counts; this pattern is overlaid with
      // waves of dimness that also scroll (at twice the speed)
      maxLoops = 250;
      gradient();
      //delay(6);  // add an extra 6ms delay to slow things down
      break;
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

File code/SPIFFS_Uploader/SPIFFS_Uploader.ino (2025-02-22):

#include <WiFi.h>
#include <AsyncTCP.h>
#include <ESPAsyncWebServer.h>
#include <SPIFFS.h>
#include "webpages.h"

#define FIRMWARE_VERSION "v0.0.1"

const String default_ssid = "...";
const String default_wifipassword = "...";
const String default_httpuser = "admin";
const String default_httppassword = "admin";
const int default_webserverporthttp = 80;

// configuration structure
struct Config {
  String ssid;               // wifi ssid
  String wifipassword;       // wifi password
  String httpuser;           // username to access web admin
  String httppassword;       // password to access web admin
  int webserverporthttp;     // http port number for web admin
};

// variables
Config config;                        // configuration
bool shouldReboot = false;            // schedule a reboot
AsyncWebServer *server;               // initialise webserver

// function defaults
String listFiles(bool ishtml = false);

void setup() {
  Serial.begin(115200);

  Serial.print("Firmware: "); Serial.println(FIRMWARE_VERSION);

  Serial.println("Booting ...");

  Serial.println("Mounting SPIFFS ...");
  if (!SPIFFS.begin(true)) {
    // if you have not used SPIFFS before on a ESP32, it will show this error.
    // after a reboot SPIFFS will be configured and will happily work.
    Serial.println("ERROR: Cannot mount SPIFFS, Rebooting");
    rebootESP("ERROR: Cannot mount SPIFFS, Rebooting");
  }

  Serial.print("SPIFFS Free: "); Serial.println(humanReadableSize((SPIFFS.totalBytes() - SPIFFS.usedBytes())));
  Serial.print("SPIFFS Used: "); Serial.println(humanReadableSize(SPIFFS.usedBytes()));
  Serial.print("SPIFFS Total: "); Serial.println(humanReadableSize(SPIFFS.totalBytes()));

  Serial.println(listFiles());

  Serial.println("Loading Configuration ...");

  config.ssid = default_ssid;
  config.wifipassword = default_wifipassword;
  config.httpuser = default_httpuser;
  config.httppassword = default_httppassword;
  config.webserverporthttp = default_webserverporthttp;

  Serial.print("\nConnecting to Wifi: ");
  WiFi.begin(config.ssid.c_str(), config.wifipassword.c_str());
  while (WiFi.status() != WL_CONNECTED) {
    delay(500);
    Serial.print(".");
  }

  Serial.println("\n\nNetwork Configuration:");
  Serial.println("----------------------");
  Serial.print("         SSID: "); Serial.println(WiFi.SSID());
  Serial.print("  Wifi Status: "); Serial.println(WiFi.status());
  Serial.print("Wifi Strength: "); Serial.print(WiFi.RSSI()); Serial.println(" dBm");
  Serial.print("          MAC: "); Serial.println(WiFi.macAddress());
  Serial.print("           IP: "); Serial.println(WiFi.localIP());
  Serial.print("       Subnet: "); Serial.println(WiFi.subnetMask());
  Serial.print("      Gateway: "); Serial.println(WiFi.gatewayIP());
  Serial.print("        DNS 1: "); Serial.println(WiFi.dnsIP(0));
  Serial.print("        DNS 2: "); Serial.println(WiFi.dnsIP(1));
  Serial.print("        DNS 3: "); Serial.println(WiFi.dnsIP(2));
  Serial.println();

  // configure web server
  Serial.println("Configuring Webserver ...");
  server = new AsyncWebServer(config.webserverporthttp);
  configureWebServer();

  // startup web server
  Serial.println("Starting Webserver ...");
  server->begin();
}

void loop() {
  // reboot if we've told it to reboot
  if (shouldReboot) {
    rebootESP("Web Admin Initiated Reboot");
  }
}

void rebootESP(String message) {
  Serial.print("Rebooting ESP32: "); Serial.println(message);
  ESP.restart();
}

// list all of the files, if ishtml=true, return html rather than simple text
String listFiles(bool ishtml) {
  String returnText = "";
  Serial.println("Listing files stored on SPIFFS");
  File root = SPIFFS.open("/");
  File foundfile = root.openNextFile();
  if (ishtml) {
    returnText += "<table><tr><th align='left'>Name</th><th align='left'>Size</th><th></th><th></th></tr>";
  }
  while (foundfile) {
    if (ishtml) {
      returnText += "<tr align='left'><td>" + String(foundfile.name()) + "</td><td>" + humanReadableSize(foundfile.size()) + "</td>";
      returnText += "<td><button onclick=\"downloadDeleteButton(\'" + String(foundfile.name()) + "\', \'download\')\">Download</button>";
      returnText += "<td><button onclick=\"downloadDeleteButton(\'" + String(foundfile.name()) + "\', \'delete\')\">Delete</button></tr>";
    } else {
      returnText += "File: " + String(foundfile.name()) + " Size: " + humanReadableSize(foundfile.size()) + "\n";
    }
    foundfile = root.openNextFile();
  }
  if (ishtml) {
    returnText += "</table>";
  }
  root.close();
  foundfile.close();
  return returnText;
}

// Make size of files human readable
// source: https://github.com/CelliesProjects/minimalUploadAuthESP32
String humanReadableSize(const size_t bytes) {
  if (bytes < 1024) return String(bytes) + " B";
  else if (bytes < (1024 * 1024)) return String(bytes / 1024.0) + " KB";
  else if (bytes < (1024 * 1024 * 1024)) return String(bytes / 1024.0 / 1024.0) + " MB";
  else return String(bytes / 1024.0 / 1024.0 / 1024.0) + " GB";
}
